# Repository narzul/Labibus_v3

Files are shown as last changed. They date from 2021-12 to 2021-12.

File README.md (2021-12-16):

Labibus_v3

Ref: https://labitat.dk/wiki/Labibus

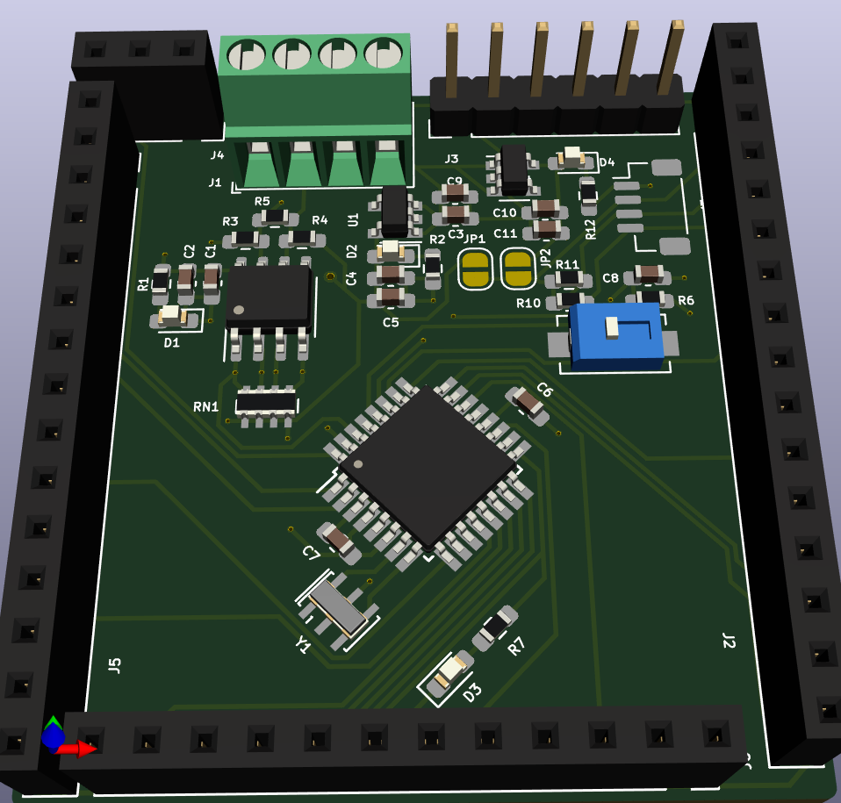
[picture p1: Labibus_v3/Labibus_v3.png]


price components around: 12 EUR
can be cheaper in bulk

|Reference |Quantity|Value |Price|
|---|---|---|-----|
|C1 C3 C4 |3 |10uF |0.3  |
|C2 C5 C6 C7 |4 |0.1uF |0.4  |
|D1 D2 D3 |3 |LED |0.3  |
|J1 |1 |Screw_Terminal_01x04|2.52 |
|J2 |1 |Conn_01x16 |0.992|
|J3 |1 |Conn_01x06 |0.372|
|J4 |1 |Conn_01x03 |0.186|
|J5 |1 |Conn_01x15 |0.93 |
|J6 |1 |Conn_01x12 |0.744|
|R1 R2 |2 |1k |0.2  |
|R8 R9 |2 |10k |0.2  |
|R3 R4 |2 |20k |0.2  |
|R5 |1 |120 |0.1  |
|R6 |1 |100k |0.1  |
|R7 |1 |300 |0.1  |
|RN1 |1 |10k |0.09 |
|SW1 |1 |SW_Push |0.123|
|U1 |1 |MIC5205-5.0YM5 |0.455|
|U2 |1 |MAX485E |2.62 |
|U3 |1 |ATmega328P-AU |2.21 |
|Y1 |1 |Crystal_GND2_Small  |0.245|
| | | |12.387|

1. Update the difference protocolls
2. Install in the bunker, with sensors
3. make a case
4. Do workshop

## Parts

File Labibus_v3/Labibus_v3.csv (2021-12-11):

Reference | Quantity | Value | Footprint | Datasheet | Price
C1 C3 C4 | 3 | 10uF | Capacitor_SMD:C_0603_1608Metric_Pad1.08x0.95mm_HandSolder | ~ | 0.3
C2 C5 C6 C7 | 4 | 0.1uF | Capacitor_SMD:C_0603_1608Metric_Pad1.08x0.95mm_HandSolder | ~ | 0.4
D1 D2 D3 | 3 | LED | LED_SMD:LED_0603_1608Metric_Pad1.05x0.95mm_HandSolder | ~ | 0.3
J1 | 1 | Screw_Terminal_01x04 | TerminalBlock_Phoenix:TerminalBlock_Phoenix_MPT-0,5-4-2.54_1x04_P2.54mm_Horizontal | ENG_CD_282834_C1-2036351.pdf | 2.52
J2 | 1 | Conn_01x16 | Connector_PinSocket_2.54mm:PinSocket_1x16_P2.54mm_Vertical | ~ | 0.992
J3 | 1 | Conn_01x06 | Connector_PinHeader_2.54mm:PinHeader_1x06_P2.54mm_Vertical | ~ | 0.372
J4 | 1 | Conn_01x03 | Connector_PinSocket_2.54mm:PinSocket_1x03_P2.54mm_Vertical | ~ | 0.186
J5 | 1 | Conn_01x15 | Connector_PinSocket_2.54mm:PinSocket_1x15_P2.54mm_Vertical | ~ | 0.93
J6 | 1 | Conn_01x12 | Connector_PinSocket_2.54mm:PinSocket_1x12_P2.54mm_Vertical | ~ | 0.744
R1 | 1 | 1k | Resistor_SMD:R_0603_1608Metric_Pad0.98x0.95mm_HandSolder | ~ | 0.1
R2 R8 R9 | 3 | 10k | Resistor_SMD:R_0603_1608Metric_Pad0.98x0.95mm_HandSolder | ~ | 0.3
R3 R4 | 2 | 20k | Resistor_SMD:R_0603_1608Metric_Pad0.98x0.95mm_HandSolder | ~ | 0.2
R5 | 1 | 120 | Resistor_SMD:R_0603_1608Metric_Pad0.98x0.95mm_HandSolder | ~ | 0.1
R6 | 1 | 100k | Resistor_SMD:R_0603_1608Metric_Pad0.98x0.95mm_HandSolder | ~ | 0.1
R7 | 1 | 300 | Resistor_SMD:R_0603_1608Metric_Pad0.98x0.95mm_HandSolder | ~ | 0.1
RN1 | 1 | 10k | Resistor_SMD:R_Array_Concave_4x0603 | Yageo-YC164-JR-0710KL-datasheet.pdf | 0.09
SW1 | 1 | SW_Push | Button_Switch_SMD:SW_SPST_EVQPE1 | pts636-1550567.pdf | 0.123
U1 | 1 | MIC5205-5.0YM5 | Package_TO_SOT_SMD:SOT-23-5 | 20005785A.pdf | 0.455
U2 | 1 | MAX485E | Package_SO:SOIC-8_3.9x4.9mm_P1.27mm | MAX485-datasheet.pdf | 2.62
U3 | 1 | ATmega328P-AU | Package_QFP:TQFP-32_7x7mm_P0.8mm | Atmega48A_PA_88A_PA_168A_PA_328_P_DS_DS40002061B-1900559.pdf | 2.21
Y1 | 1 | Crystal_GND2_Small | Crystal:Resonator_SMD_muRata_CSTxExxV-3Pin_3.0x1.1mm_HandSoldering | SPEC-CSTNE16M0V530000R0.pdf | 0.245
 |  |  |  |  | 12.387

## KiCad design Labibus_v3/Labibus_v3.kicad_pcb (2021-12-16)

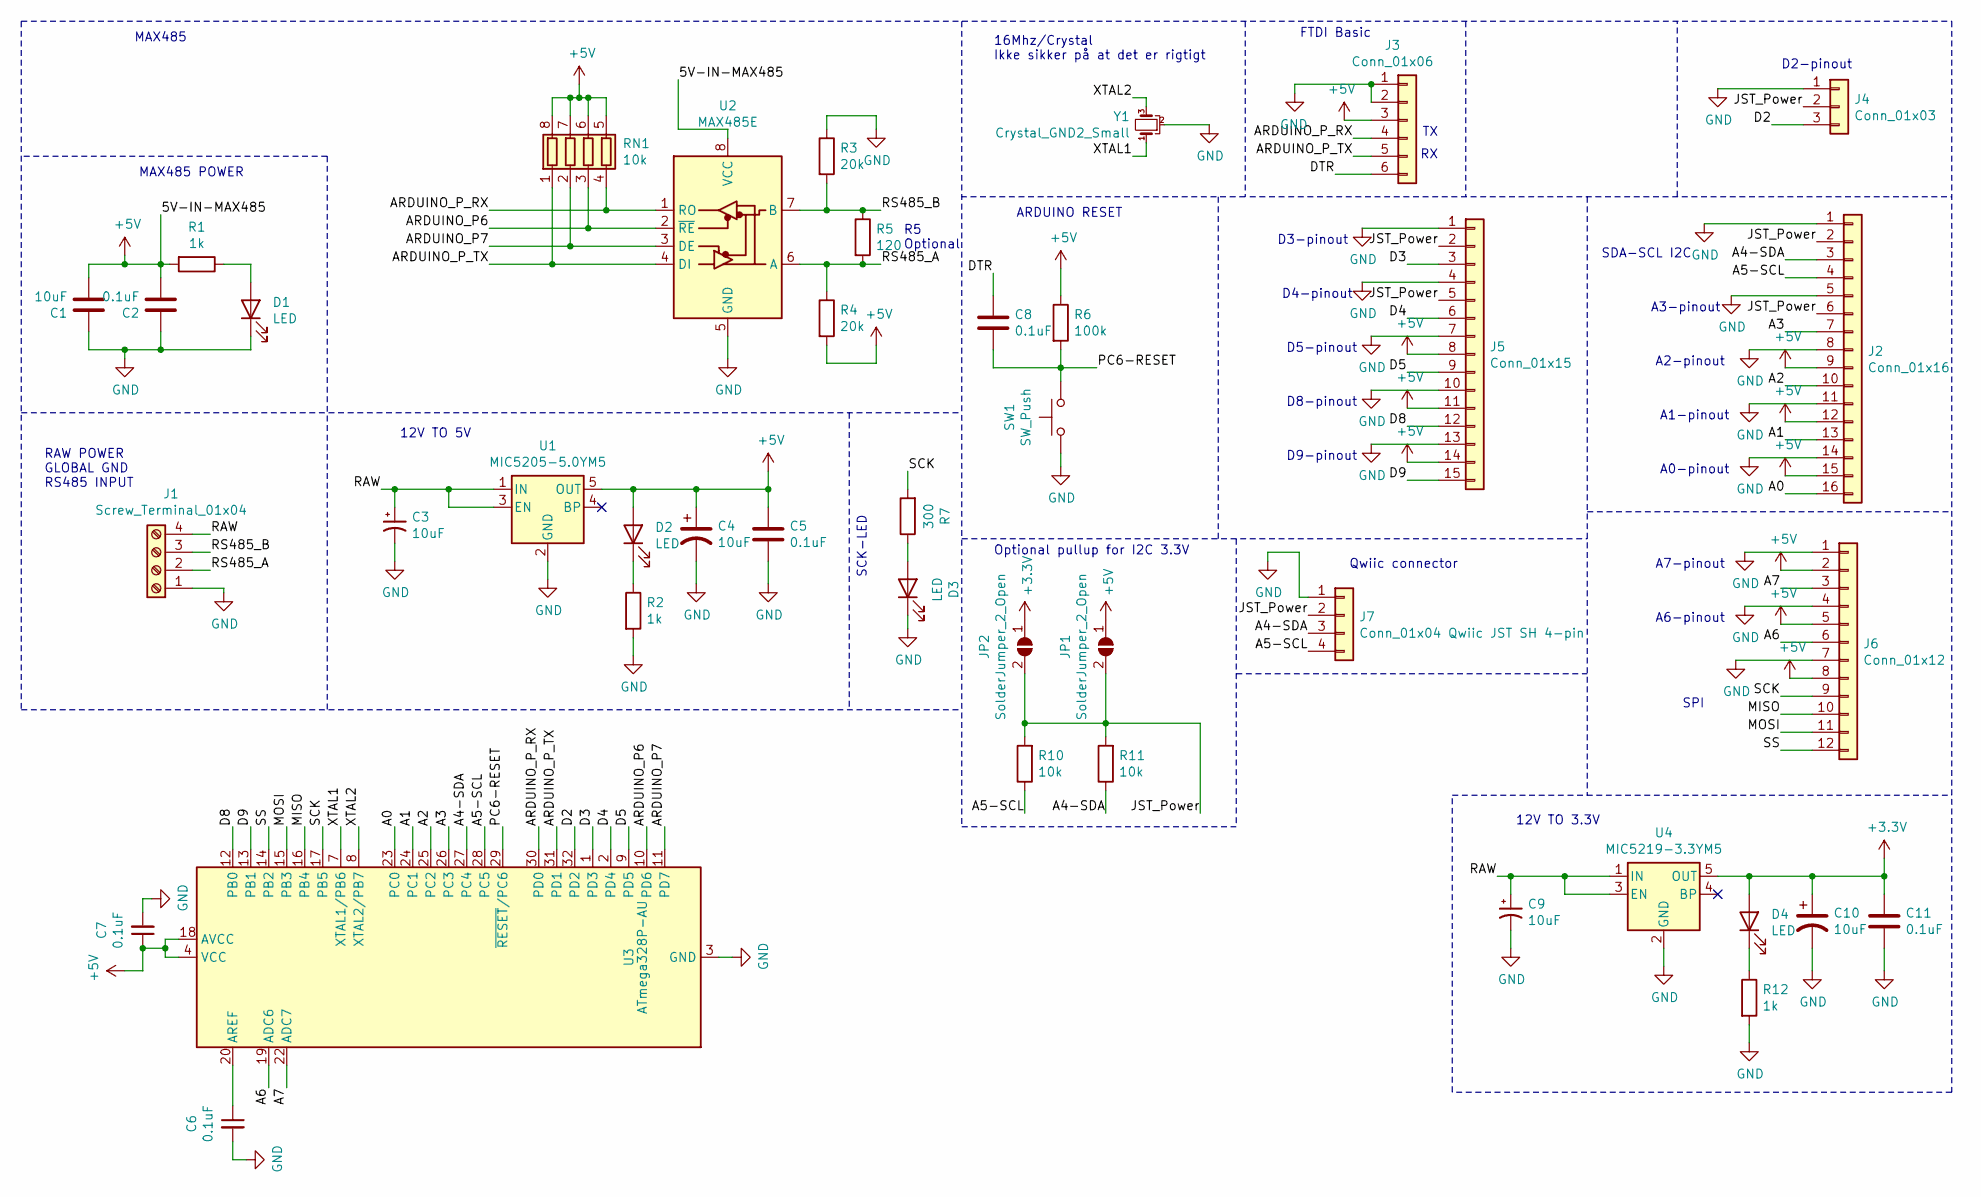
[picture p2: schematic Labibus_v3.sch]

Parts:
C1, C3, C4, C9, C10: 10uF; C_0603_1608Metric_Pad1.08x0.95mm_HandSolder
C2, C5, C6, C7, C8, C11: 0.1uF; C_0603_1608Metric_Pad1.08x0.95mm_HandSolder
D1, D2, D3, D4: LED; LED_0603_1608Metric_Pad1.05x0.95mm_HandSolder
J1: Screw_Terminal_01x04; TerminalBlock_Phoenix_MPT-0,5-4-2.54_1x04_P2.54mm_Horizontal
J2: Conn_01x16; PinSocket_1x16_P2.54mm_Vertical
J3: Conn_01x06; PinHeader_1x06_P2.54mm_Vertical
J4: Conn_01x03; PinSocket_1x03_P2.54mm_Vertical
J5: Conn_01x15; PinSocket_1x15_P2.54mm_Vertical
J6: Conn_01x12; PinSocket_1x12_P2.54mm_Vertical
J7: Conn_01x04 Qwiic JST SH 4-pin; JST_SH_BM04B-SRSS-TB_1x04-1MP_P1.00mm_Vertical
JP1, JP2: SolderJumper_2_Open; SolderJumper-2_P1.3mm_Open_RoundedPad1.0x1.5mm
R1, R2, R12: 1k; R_0603_1608Metric_Pad0.98x0.95mm_HandSolder
R3, R4: 20k; R_0603_1608Metric_Pad0.98x0.95mm_HandSolder
R5: 120; R_0603_1608Metric_Pad0.98x0.95mm_HandSolder
R6: 100k; R_0603_1608Metric_Pad0.98x0.95mm_HandSolder
R7: 300; R_0603_1608Metric_Pad0.98x0.95mm_HandSolder
R10, R11: 10k; R_0603_1608Metric_Pad0.98x0.95mm_HandSolder
RN1: 10k; R_Array_Concave_4x0603
SW1: SW_Push; SW_SPST_EVQPE1
U1: MIC5205-5.0YM5; SOT-23-5
U2: MAX485E; SOIC-8_3.9x4.9mm_P1.27mm
U3: ATmega328P-AU; TQFP-32_7x7mm_P0.8mm
U4: MIC5219-3.3YM5; SOT-23-5
Y1: Crystal_GND2_Small; Resonator_SMD_muRata_CSTxExxV-3Pin_3.0x1.1mm_HandSoldering

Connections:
+3V3: C10.1, C11.1, D4.2 (A), JP2.1 (A), U4.5 (OUT)
+5V: C1.2, C2.2, C4.1, C5.1, C7.1, D2.2 (A), J2.9, J2.12, J2.15, J3.3, J5.8, J5.11, J5.14, J6.2, J6.5, J6.8, JP1.1 (A), R1.2, R4.2, R6.1, RN1.5 (R4.2), RN1.6 (R3.2), RN1.7 (R2.2), RN1.8 (R1.2), U1.5 (OUT), U2.8 (VCC), U3.4 (VCC), U3.6 (VCC), U3.18 (AVCC)
/A0: J2.16, U3.23 (PC0)
/A1: J2.13, U3.24 (PC1)
/A2: J2.10, U3.25 (PC2)
/A3: J2.7, U3.26 (PC3)
/A4-SDA: J2.3, J7.3, R11.1, U3.27 (PC4)
/A5-SCL: J2.4, J7.4, R10.1, U3.28 (PC5)
/A6: J6.6, U3.19 (ADC6)
/A7: J6.3, U3.22 (ADC7)
/ARDUINO_P6: RN1.3 (R3.1), U2.2 (~RE), U3.10 (PD6)
/ARDUINO_P7: RN1.2 (R2.1), U2.3 (DE), U3.11 (PD7)
/ARDUINO_P_RX: J3.4, RN1.4 (R4.1), U2.1 (RO), U3.30 (PD0)
/ARDUINO_P_TX: J3.5, RN1.1 (R1.1), U2.4 (DI), U3.31 (PD1)
/D2: J4.3, U3.32 (PD2)
/D3: J5.3, U3.1 (PD3)
/D4: J5.6, U3.2 (PD4)
/D5: J5.9, U3.9 (PD5)
/D8: J5.12, U3.12 (PB0)
/D9: J5.15, U3.13 (PB1)
/DTR: C8.2, J3.6
/JST_Power: J2.2, J2.6, J4.2, J5.2, J5.5, J7.2, JP1.2 (B), JP2.2 (B), R10.2, R11.2
/MISO: J6.10, U3.16 (PB4)
/MOSI: J6.11, U3.15 (PB3)
/PC6-RESET: C8.1, R6.2, SW1.2, U3.29 (~RESET~/PC6)
/RAW: C3.1, C9.1, J1.4, U1.1 (IN), U1.3 (EN), U4.1 (IN), U4.3 (EN)
/RS485_A: J1.2, R4.1, R5.2, U2.6 (A)
/RS485_B: J1.3, R3.2, R5.1, U2.7 (B)
/SCK: J6.9, R7.2, U3.17 (PB5)
/SS: J6.12, U3.14 (PB2)
/XTAL1: U3.7 (XTAL1/PB6), Y1.1
/XTAL2: U3.8 (XTAL2/PB7), Y1.3
GND: C1.1, C2.1, C3.2, C4.2, C5.2, C6.2, C7.2, C9.2, C10.2, C11.2, D1.1 (K), D3.1 (K), J1.1, J2.1, J2.5, J2.8, J2.11, J2.14, J3.1, J3.2, J4.1, J5.1, J5.4, J5.7, J5.10, J5.13, J6.1, J6.4, J6.7, J7.1, R2.2, R3.1, R12.2, SW1.1, U1.2 (GND), U2.5 (GND), U3.3 (GND), U3.5 (GND), U3.21 (GND), U4.2 (GND), Y1.2
unnamed: C6.1, U3.20 (AREF)
unnamed: D1.2 (A), R1.1
unnamed: D2.1 (K), R2.1
unnamed: D3.2 (A), R7.1
unnamed: D4.1 (K), R12.1

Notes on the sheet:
16Mhz/Crystal Ikke sikker på at det er rigtigt
MAX485
MAX485 POWER
RAW POWER GLOBAL GND RS485 INPUT
12V TO 5V
FTDI Basic
SPI
ARDUINO RESET
SCK-LED
D3-pinout
D2-pinout
D5-pinout
D4-pinout
D8-pinout
D9-pinout
A6-pinout
A7-pinout
A0-pinout
SDA-SCL I2C
A1-pinout
A2-pinout
A3-pinout
R5 Optional
12V TO 3.3V
Optional pullup for I2C 3.3V
Qwiic connector

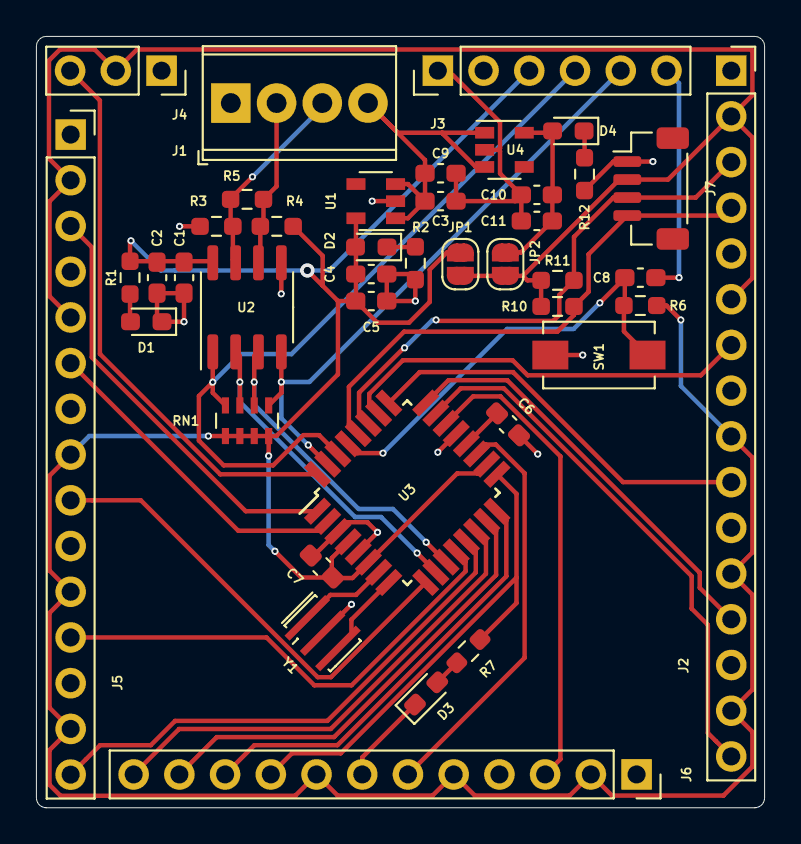
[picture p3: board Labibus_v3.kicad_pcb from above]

Board: 2 copper layers, 40.5 x 42.9 mm, 41 parts (0 on the bottom side), 38 nets.

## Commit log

2021-12-03 Start some datasheet added. -More needs to be added Started om sch and almost done.
    [Labibus_v3.kicad_pcb, Labibus_v3.sch]
2021-12-09 update started on first pcb layout
    [Labibus_v3.sch]
2021-12-11 new update to the pcb layout Note: Change pin row to 13 on the left side to shrink the size
    [Labibus_v3.kicad_pcb, Labibus_v3.sch]
2021-12-11 added tabel and price. board version 1.2
    [Labibus_v3.csv, Labibus_v3.kicad_pcb, Labibus_v3.sch]
2021-12-11 update to csv and readme
    [Labibus_v3.csv]
2021-12-11 update to PCB, layout update.
    [Labibus_v3.kicad_pcb]
2021-12-16 update to the pcb. 3v3 added I2C 3.3 and 5 JST added.
    [Labibus_v3.kicad_pcb, Labibus_v3.sch]
2021-12-16 testing i can commit, i have commitment issues
    [Labibus_v3.kicad_pcb]
2021-12-16 new branch test
    [Labibus_v3.kicad_pcb]
2021-12-16 update with: 3.3V and 5V select JST connector
    [Labibus_v3.kicad_pcb, Labibus_v3.sch]
